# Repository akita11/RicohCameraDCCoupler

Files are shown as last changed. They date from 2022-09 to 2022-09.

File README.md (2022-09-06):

# Ricoh Camera DC Coupler

DC power supply coupler for Ricoh WG-10. Supply 7V or above to operate WG-10.

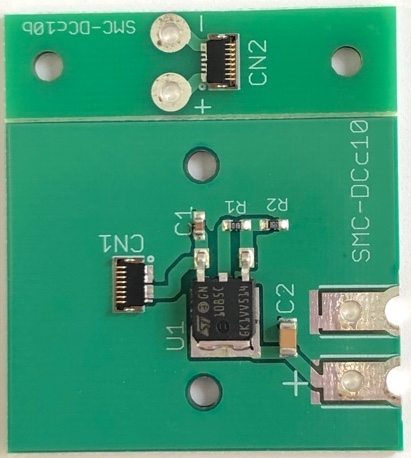
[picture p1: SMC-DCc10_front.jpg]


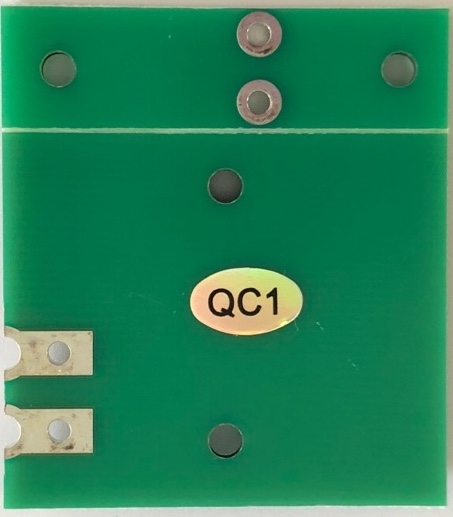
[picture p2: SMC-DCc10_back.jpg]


## Build

- fabricate PCB using "SMC-DCc10_gerber.zip" (original design using Eagle, PCB specs are shown in "SMC-DCc10_BOM.xlsx".), and divide into two sub-boards. (smaller one is outside WG-10 to attach external power cable, larger one is DC coupler attached in WG-10's battery area.)
- solder components listed in  "SMC-DCc10_BOM.xlsx".
- additional component: [FPC cable](https://www.digikey.jp/ja/products/detail/molex-llc/0151660079/3280961)

## Author

Junichi Akita (akita@ifdl.jp)

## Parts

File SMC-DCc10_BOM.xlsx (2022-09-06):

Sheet: PCB Specification
Your PCB Specification
PCB Quantity | 90pcs
Layer | 2layer
PCB Thickness | 1.6mm
Dimensions | 45mmx40mm
Castellated Hole | Yes
PCB Color | Green
Surface Finish | HASL Lead Free
Copper Weight | 1oz
Text Color | White
Different Design | 1
Please find more PCB information on our on-line PCB ordering Page
https://www.elecrow.com/pcb-manufacturing.html

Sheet: BOM
USBload2
# | Reference | QTY | Value | Package | Manufacturer Part number | Description | SMD | THT | Original | Elecrow PN | Note
1 | CN1,CN2 | 2 |  |  | WM9076CT-ND | FPC connector | 4 |  |  |  | Molex 5014610812
2 | C1 | 1 | 0.1uF | 0603 | 311-1343-1-ND | capacitor | 2 |  |  |  | equivalent is OK
3 | C2 | 1 | 100uF/10V | 1206 | 445-6007-1-ND | capacitor | 2 |  |  |  | equivalent is OK
4 | R1 | 1 | 1k/1% | 0603 |  | resistor | 2 |  |  |  | equivalent is OK
5 | R2 | 1 | 3k/1% | 0603 |  | resistor | 2 |  |  |  | equivalent is OK
6 | U1 | 1 |  | DPAK | 497-3418-1-ND | LDO | 4 |  |  |  | STMicro, LD1085C
 |  |  |  |  |  | total： | 16 | 0
 | Declare：
 | 1、If the component should be original like Digi-key or Mouser，the component must have complete Manufacture part number

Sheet: Position File
Designator | Footprint | Center-X(mm) | Center-Y(mm) | Layer | Rotation
C1 | C0603 | 22.86 | 20.32 | TopLayer | 0
C2 | C1206 | 11.43 | 11.43 | TopLayer | 0
CN1 | FPC05mm | 17 | 25.75 | TopLayer | 180
CN2 | FPC05mm | 39.5 | 19.25 | TopLayer | 0
R1 | R0603 | 22.86 | 16.51 | TopLayer | 90
R2 | R0603 | 22.86 | 12.7 | TopLayer | 90
U1 | SOT22-3 | 16.26 | 17.78 | TopLayer | 90

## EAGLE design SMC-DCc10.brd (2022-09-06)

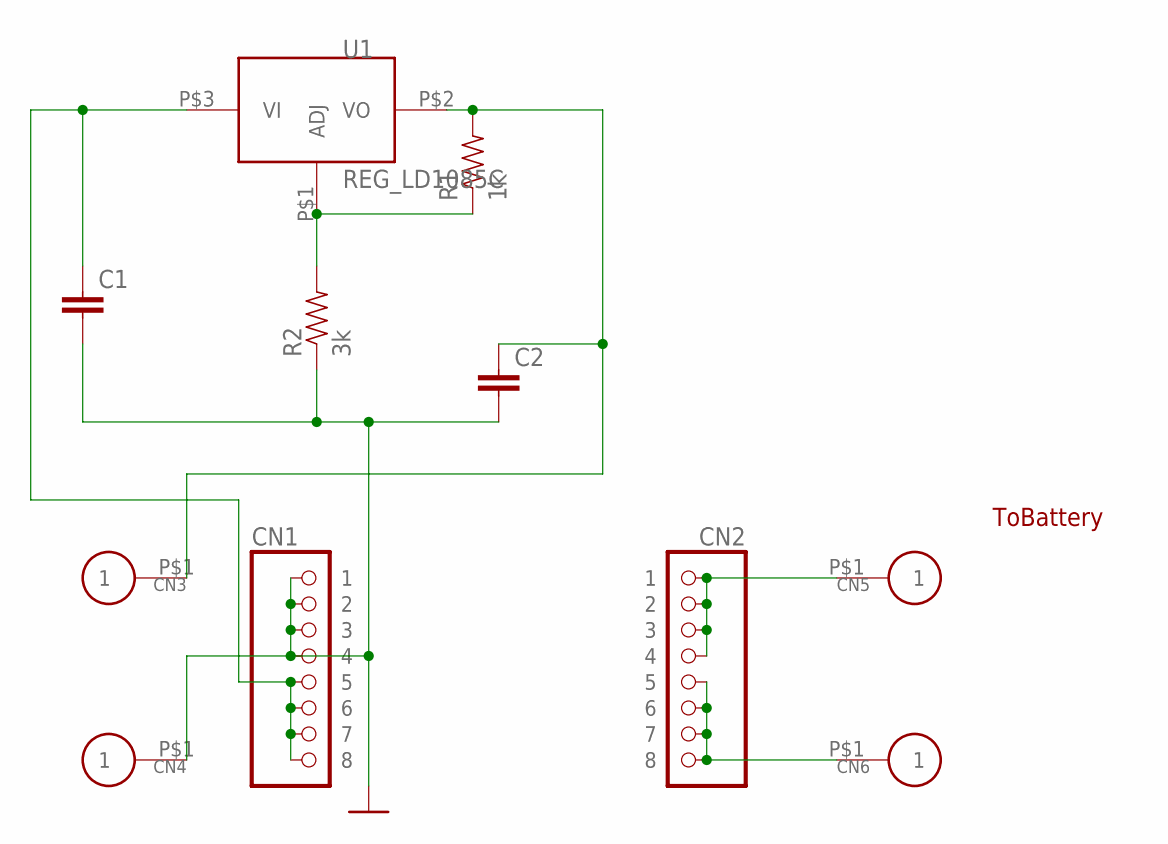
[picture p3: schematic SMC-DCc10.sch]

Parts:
C1: CAP0603; 0603
C2: CAP1206; 1206
CN1, CN2: CON_PINHD-1X8FPC05; CON_8P_FPC05MM
CN3, CN4, CN5, CN6: CON_P01SMD1MM; PAD_SMD1MM
R1: 1k; 0603
R2: 3k; 0603
U1: REG_LD1085C; TO-252-3

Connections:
GND: C1.2, C2.P$2 (2), CN1.P$1 (1), CN1.P$2 (2), CN1.P$3 (3), CN1.P$4 (4), CN4.P$1, R2.1
unnamed: CN2.P$5 (5), CN2.P$6 (6), CN2.P$7 (7), CN2.P$8 (8), CN6.P$1
unnamed: C2.P$1 (1), CN3.P$1, R1.2, U1.P$2 (VO)
unnamed: CN2.P$1 (1), CN2.P$2 (2), CN2.P$3 (3), CN2.P$4 (4), CN5.P$1
unnamed: R1.1, R2.2, U1.P$1 (ADJ)
unnamed: C1.1, CN1.P$5 (5), CN1.P$6 (6), CN1.P$7 (7), CN1.P$8 (8), U1.P$3 (VI)

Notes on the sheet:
ToBattery

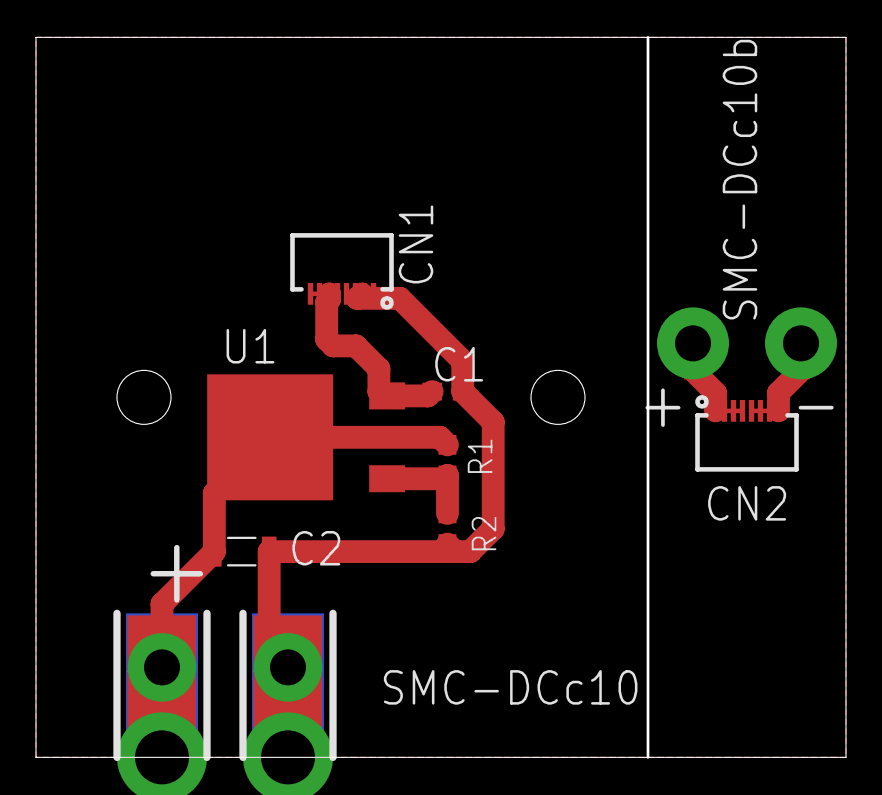
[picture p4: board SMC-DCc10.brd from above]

Board: 2 copper layers, 45.0 x 40.0 mm, 11 parts (0 on the bottom side), 6 nets.

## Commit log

2022-09-06 add DCc10
    [SMC-DCc10.brd, SMC-DCc10.sch, SMC-DCc10_BOM.xlsx]
2022-09-06 add spacer
2022-09-06 add README, photo
    [SMC-DCc5.brd, SMC-DCc5.sch, SMC-DCc5_BOM.xlsx]
